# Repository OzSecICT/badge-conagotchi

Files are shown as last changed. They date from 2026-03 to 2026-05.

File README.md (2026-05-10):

# OzSec 2026: Conagotchi

Private repository for the OzSec 2026 Conagotchi badge — an ESP32-S3 interactive badge with a round GC9A01 display, virtual pet (Conagotchi) mode, and CTF challenge mode.

## Setup

Install host tools:

```bash
pip install esptool mpremote Pillow
```

## Flashing MicroPython firmware

```bash
esptool.py --chip esp32s3 --before default-reset --after hard-reset \
    write_flash -z 0x0 firmware/ESP32_GENERIC_S3-SPIRAM_OCT-20251209-v1.27.0.bin
```

## Deploying code

```bash
mpremote cp -r source/. :
mpremote reset
```

The VS Code default task (`Ctrl+Shift+B`) does both steps automatically.

## Converting images for the display

The GC9A01 display is 240×240 pixels round. Images must be converted from PNG to raw RGB565 binary before being copied to the badge — MicroPython cannot decode PNGs at runtime.

### Install the conversion tool dependency

```bash
pip install Pillow
```

### Full-screen backgrounds (240×240)

Design your PNG at 240×240 pixels. The corners outside the circular bezel are never shown, so no special treatment is needed — just design for a circle inscribed in the square.

```bash
python tools/convert_image.py your_image.png --outdir source/img
```

Produces `source/img/your_image.bin` — 115,200 bytes (240 × 240 × 2).

### Character animation frames

The Conagotchi idle animation uses sprite frames sized to the character bounding box (100×115 px by default). Export individual frames from your animation tool as transparent-background PNGs, then convert:

```bash
# Pre-sized PNGs (100×115) — convert without resizing
python tools/convert_image.py char_idle_0.png char_idle_1.png char_idle_2.png char_idle_3.png \
    --no-resize --outdir source/img

# OR crop from a full 240×240 mockup
python tools/convert_image.py mockup_frame0.png --crop 70,52,100,115 \
    --output source/img/char_idle_0.bin
```

The `--crop` coordinates (`x,y,w,h`) match the `_CHAR_X`, `_CHAR_Y`, `_CHAR_W`, `_CHAR_H` constants in `source/screens/conagotchi.py`.

### Menu button sprites

Each navigation button has three states: unselected (baked into the background), selected, and pressed. The selected/pressed states are small sprite files:

```bash
# Pre-sized sprite PNG
python tools/convert_image.py btn_pet_sel.png --no-resize --outdir source/img

# OR crop the button region from a full 240×240 state mockup
# Coordinates match the _BUTTONS table in source/screens/menu.py
python tools/convert_image.py menu_mockup_selected.png --crop 90,5,60,45 \
    --output source/img/btn_pet_sel.bin
```

### Compositing transparent overlays

If your overlay PNG has an alpha channel (transparency), composite it onto the background before converting:

```bash
python tools/convert_image.py background.png overlay.png \
    --composite --output source/img/result.bin
```

### Deploy images to badge

Images live in `source/img/` and are deployed alongside the Python files:

```bash
mpremote cp -r source/. :
```

### Expected image files

| File | Purpose |
|---|---|
| `source/img/logo.bin` | Splash screen background |
| `source/img/{character}/background.bin` | Per-character main screen background (240×240) |
| `source/img/{character}/character.bin` | Idle animation base frame (80×80) |
| `source/img/{character}/idle_1.bin` … | Additional idle animation frames (optional) |
| `source/img/menu_bg.bin` | Menu screen background (all buttons unselected) |
| `source/img/btn_{id}_sel.bin` | Per-button selected state sprite |
| `source/img/btn_{id}_press.bin` | Per-button pressed state sprite |

The active character is set by `_CHARACTER` in `source/screens/conagotchi.py` (currently `"hackachi"`).

All `.bin` files are gitignored — generate them locally from your source PNGs.

## Hardware notes

- IR receiver to be changed to TSOP57438TT1 ([JLCPCB part](https://jlcpcb.com/partdetail/VishayIntertech-TSOP57438TT1/C3742825))

## Diagnostics

Run this on the REPL to check memory and flash:

```python
import gc, sys, esp32, os; gc.collect(); print(f"\n=== MicroPython Info ===\nImplementation: {sys.implementation}\nPlatform: {sys.platform}\nuname: {os.uname()}\n\n=== Memory ===\nFree: {gc.mem_free()/1024:.1f} KB\nUsed: {gc.mem_alloc()/1024:.1f} KB\nTotal: {(gc.mem_free()+gc.mem_alloc())/1024:.1f} KB\n\n=== Heap Regions ==="); [print(f"  {r[0]/1024/1024:.2f} MB total, {r[1]/1024/1024:.2f} MB free, {r[2]} largest block") for r in esp32.idf_heap_info(esp32.HEAP_DATA)]; print(f"\n=== Flash ==="); import esp; print(f"  Flash size: {esp.flash_size()/1024/1024:.0f} MB")
```

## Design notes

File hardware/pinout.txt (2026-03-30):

Badge pinout:

UART
GPIO43  ESP_TX
GPIO44  ESP_RX 

USB
GPIO19  Data-
GPIO20  Data+

JTAG
GPIO5   TCK
GPIO6   TDO
GPIO7   TDI
GPIO8   TMS

I2C
GPIO17  SDA
GPIO18  SCL

Buttons
GPIO0   BOOT
GPIO9   START
GPIO21  SELECT
GPIO46  RIGHT
GPIO47  LEFT

SAO
GPIO38  SAO_GPIO1
GPIO48  SAO_GPIO2

LEDs
GPIO2   ALERT
GPIO4   RAFFLE
GPIO45  RGB Strip (8)

Display/SPI
GPIO10  CS
GPIO11  SDA
GPIO12  SCL
GPIO13  DC
GPIO14  RST

Link / IR
GPIO41  IR_TX
GPIO42  IR_RX

Link / Connector
GPIO39  LINK_TX
GPIO40  LINK_RX

Free pins:
GPIO1
GPIO3

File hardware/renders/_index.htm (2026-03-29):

# Render Browser

/ OzSec2026-ESP32

14 variants · 2 views each

Front Back

## All variants — front view

Black mask / White silk / ENIG (Gold)

Black Gold

Black mask / White silk / HASL (Silver)

Black Silver

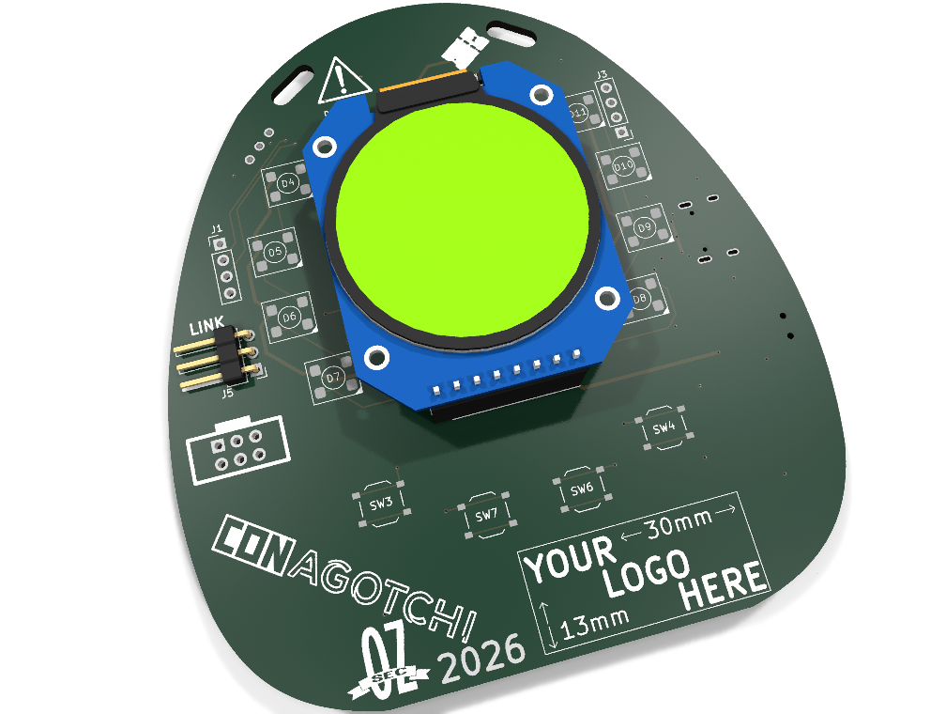
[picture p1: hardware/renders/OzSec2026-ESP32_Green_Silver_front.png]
Green mask / White silk / HASL (Silver)


Green Silver

Purple mask / White silk / HASL (Silver)

Purple Silver

Red mask / White silk / HASL (Silver)

Red Silver

Yellow mask / White silk / HASL (Silver)

Yellow Silver

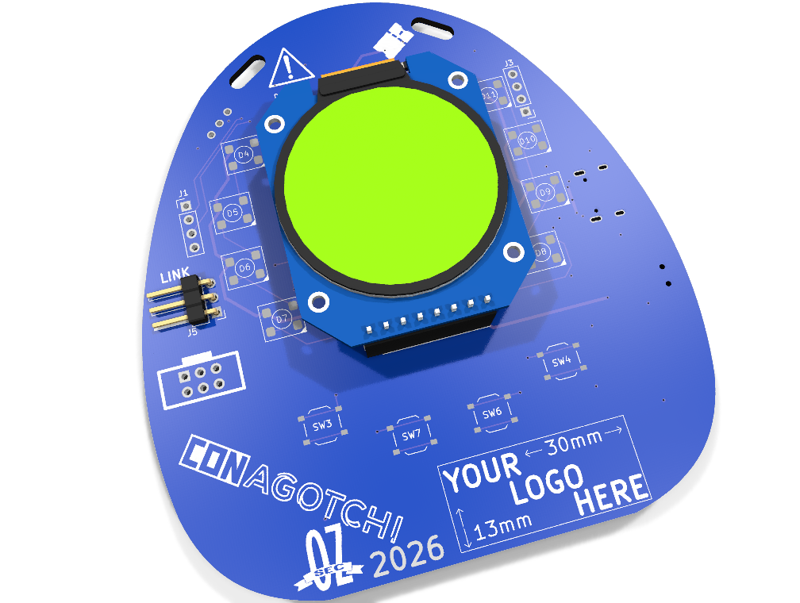
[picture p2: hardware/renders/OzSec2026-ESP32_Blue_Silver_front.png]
Blue mask / White silk / HASL (Silver)


Blue Silver

White mask / Black silk / HASL (Silver)

White Silver

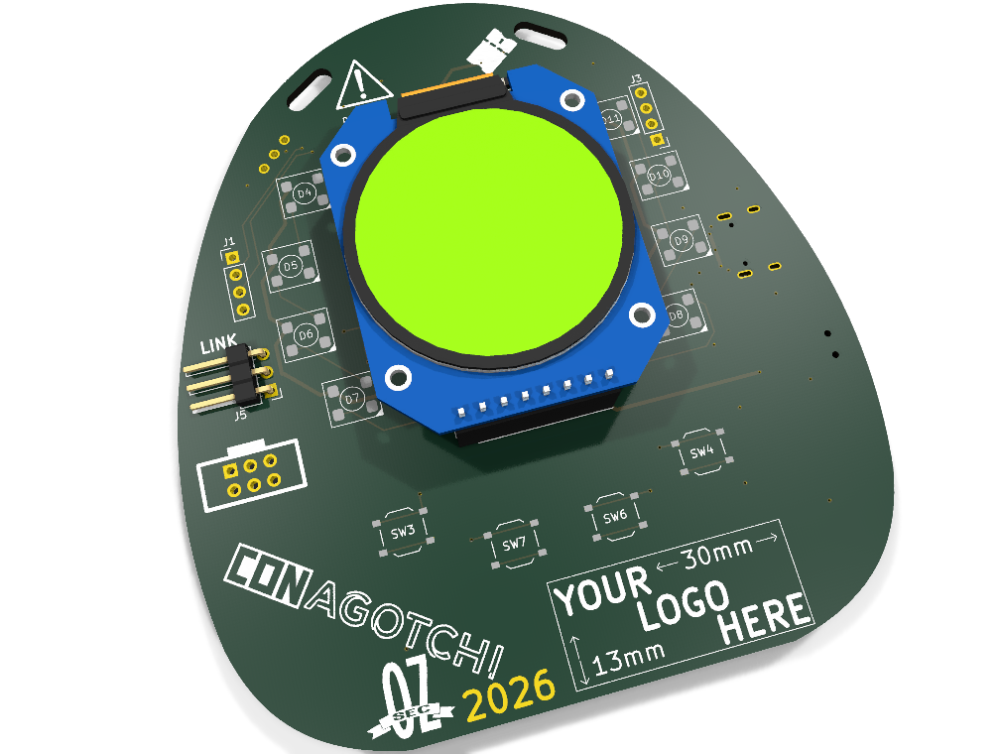
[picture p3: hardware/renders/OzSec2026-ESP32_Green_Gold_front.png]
Green mask / White silk / ENIG (Gold)


Green Gold

Purple mask / White silk / ENIG (Gold)

Purple Gold

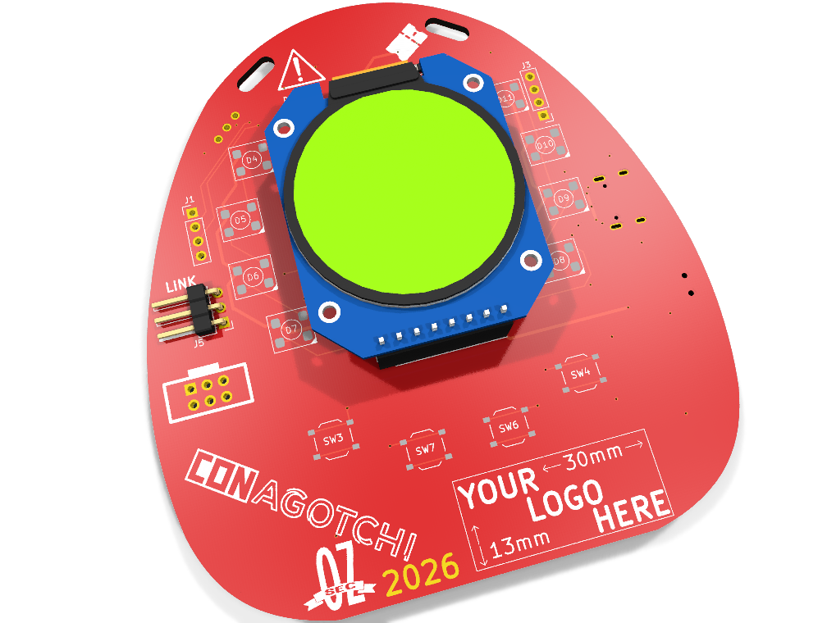
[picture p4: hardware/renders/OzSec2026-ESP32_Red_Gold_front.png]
Red mask / White silk / ENIG (Gold)


Red Gold

Yellow mask / White silk / ENIG (Gold)

Yellow Gold

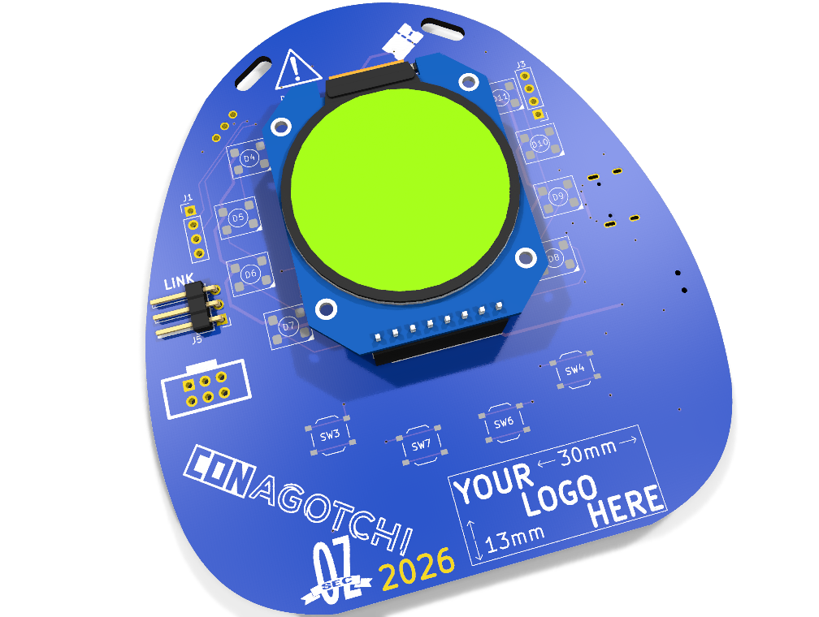
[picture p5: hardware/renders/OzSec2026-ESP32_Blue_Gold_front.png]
Blue mask / White silk / ENIG (Gold)


Blue Gold

White mask / Black silk / ENIG (Gold)

White Gold

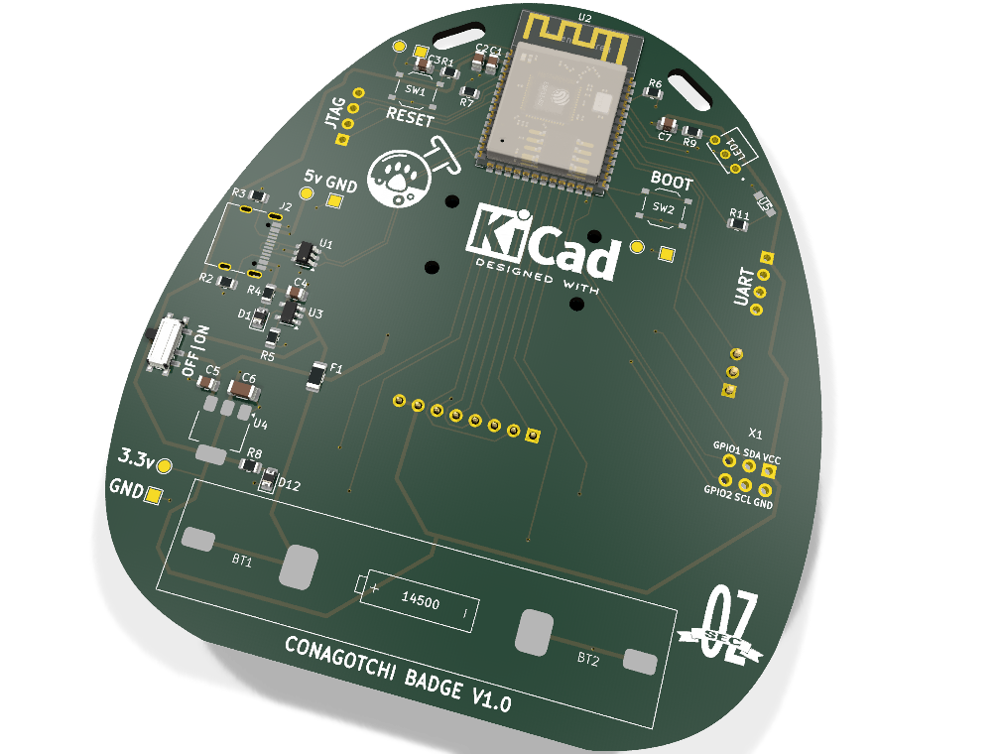
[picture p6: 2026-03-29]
hardware/renders/OzSec2026-ESP32_Green_Gold_back.png

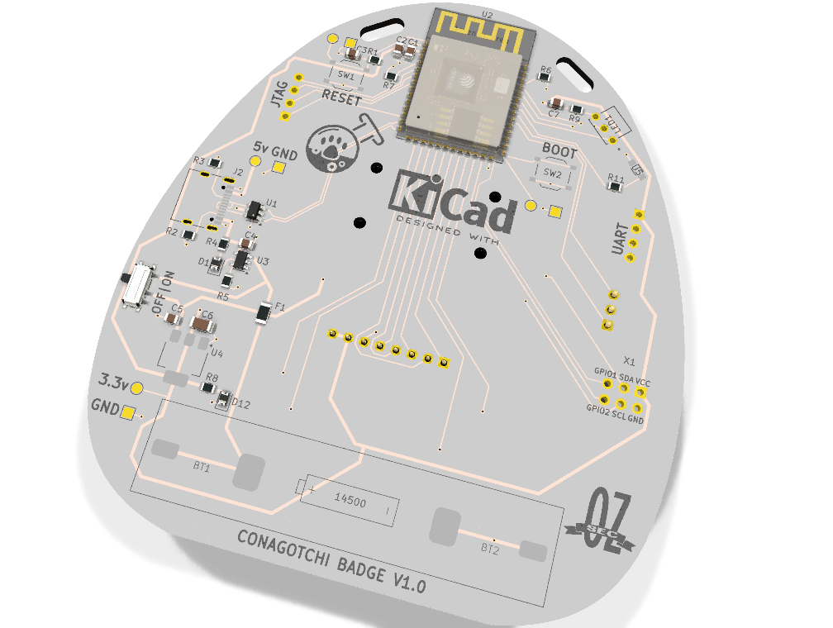
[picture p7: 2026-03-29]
hardware/renders/OzSec2026-ESP32_White_Gold_back.png

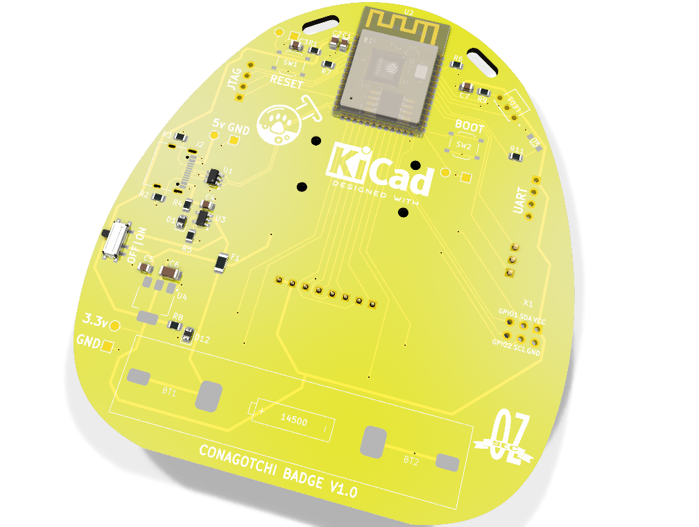
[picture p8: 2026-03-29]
hardware/renders/OzSec2026-ESP32_Yellow_Gold_back.png

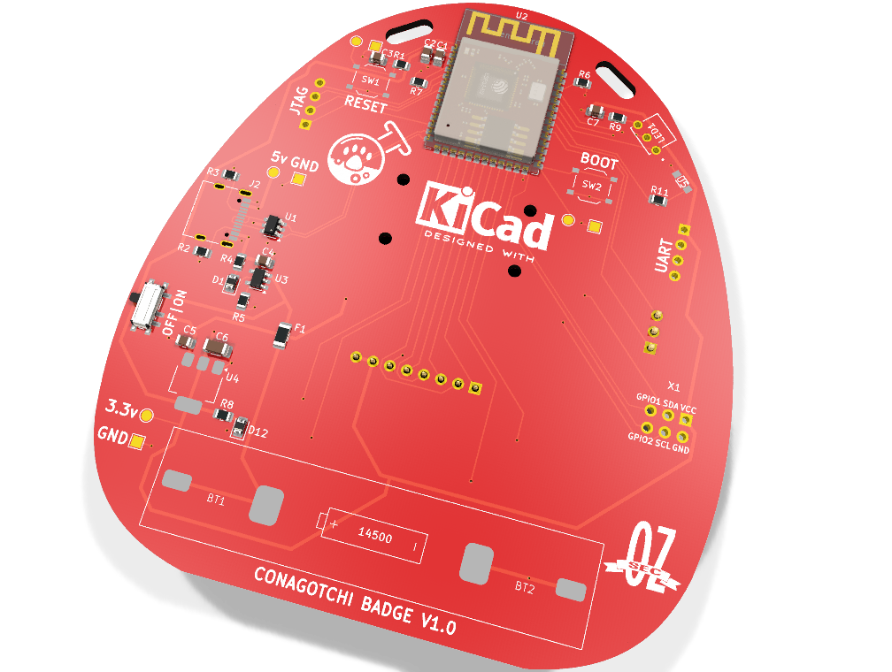
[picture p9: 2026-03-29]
hardware/renders/OzSec2026-ESP32_Red_Gold_back.png

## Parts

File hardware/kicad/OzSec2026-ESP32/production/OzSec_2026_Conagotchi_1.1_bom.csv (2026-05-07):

Designator | Footprint | Quantity | Value | LCSC Part #
BT1_2 | MY-AA-04_Silkscreen_Only | 1 | Battery | C2979179
BT1 | MY-AA-04_BT1A | 1 | ~ | C2979179
BT2 | MY-AA-04_BT1B | 1 | ~ | C2979179
C1 | 0805 | 1 | 22uF | C45783
C2, C6 | 0805 | 2 | 100nF | C49678
C3 | 0805 | 1 | 10uF | C15850
C4 | 0805 | 1 | 1uF | C28323
C5 | 0805 | 1 | 4.7uF | C1779
C7 | 1206 | 1 | 100uF | C15008
D1 | LED_MB14940_VIS | 1 | VSMY14940 | C511069
D10, D11, D12, D5, D6, D7, D8, D9 | D_SMD5050-4P_XL-5050RGBC-2812B | 8 | 2812B | C2843785
D13, D4 | 0805 | 2 | Green | C2297
D2, D3 | 0805 | 2 | Yellow | C2296
F1 | 1206 | 1 | Fuse | C261957
J2 | USB_C_Receptacle_G-Switch_GT-USB-7010ASV | 1 | USB_C_Receptacle_USB2.0 | C2988369
J4 | PinSocket_1x08_P2.54mm_Vertical | 1 | DISPLAY | C42431840
J5 | PinHeader_1x03_P2.54mm_Horizontal | 1 | Conn_01x03_Socket | C492411
R1, R10 | 0805 | 2 | 10k | C17414
R2, R3 | 0805 | 2 | 5.1K | C27834
R4, R6 | 0805 | 2 | 100 | C17408
R5, R8, R9 | 0805 | 3 | 1K | C17513
R7 | 0805 | 1 | 2K | C17604
SW1, SW2 | SW_Push_1P1T_XKB_TS-1187A | 2 | SW_Push | C318884
SW3, SW4, SW6, SW7 | SW-SMD_4P-L4.5-W4.5-P3.00-LS6.8 | 4 | SW_Push | C2888900
SW5 | SW_SPDT_PCM12 | 1 | POWER | C431541
U1 | SOT-23-6 | 1 | USBLC6-2SC6 | C2827654
U2 | ESP32-S3-WROOM-1 | 1 | ESP32-S3-WROOM-1 | C2913201
U3 | TSOP382 | 1 | TSOP38238 | C141632
U4 | TSOT-23-5 | 1 | ME4054BM5G-N | C478383
U5 | TLV1117LV | 1 | TLV1117LV-33 | C15578

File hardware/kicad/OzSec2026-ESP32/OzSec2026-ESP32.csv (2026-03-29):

Reference | Qty | Value | DNP | Exclude from BOM | Exclude from Board | Footprint | Link | LCSC
BT1 | 1 | ~ |  |  |  | RuffLabs:MY-AA-04_BT1A
BT2 | 1 | ~ |  |  |  | RuffLabs:MY-AA-04_BT1B
C1 | 1 | 22uF |  |  |  | Capacitor_SMD:C_0805_2012Metric | https://www.lcsc.com/product-detail/C45783.html | C45783
C2,C5 | 2 | 100nF |  |  |  | Capacitor_SMD:C_0805_2012Metric | https://www.lcsc.com/product-detail/C49678.html | C49678
C3 | 1 | 10uF |  |  |  | Capacitor_SMD:C_0805_2012Metric | https://www.lcsc.com/product-detail/C15850.html | C15850
C4 | 1 | 1uF |  |  |  | Capacitor_SMD:C_0805_2012Metric | https://www.lcsc.com/product-detail/C28323.html | C28323
C6 | 1 | 100uF |  |  |  | Capacitor_SMD:C_1206_3216Metric | https://www.lcsc.com/product-detail/C15008.html | C15008
D1,D2 | 2 | Yellow |  |  |  | Diode_SMD:D_0805_2012Metric | https://www.lcsc.com/product-detail/C2296.html | C2296
D3,D12 | 2 | Green |  |  |  | Diode_SMD:D_0805_2012Metric | https://www.lcsc.com/product-detail/C2296.html | C2297
D4,D5,D6,D7,D8,D9,D10,D11 | 8 | 2812B |  |  |  | RuffLabs:D_SMD5050-4P_XL-5050RGBC-2812B | https://www.lcsc.com/product-detail/C2843785.html | C2843785
F1 | 1 | Fuse |  |  |  | Fuse:Fuse_1206_3216Metric | https://www.lcsc.com/product-detail/C261957.html | C261957
J1 | 1 | UART | DNP |  |  | Connector_PinHeader_2.54mm:PinHeader_1x04_P2.54mm_Vertical
J2 | 1 | USB_C_Receptacle_USB2.0 |  |  |  | Connector_USB:USB_C_Receptacle_G-Switch_GT-USB-7010ASV | https://www.lcsc.com/product-detail/C2988369.html | C2988369
J3 | 1 | JTAG | DNP |  |  | Connector_PinHeader_2.54mm:PinHeader_1x04_P2.54mm_Vertical
J4 | 1 | DISPLAY |  |  |  | Connector_PinSocket_2.54mm:PinSocket_1x08_P2.54mm_Vertical
R1 | 1 | 10k |  |  |  | Resistor_SMD:R_0805_2012Metric | https://www.lcsc.com/product-detail/C17414.html | C17414
R2,R3 | 2 | 5.1K |  |  |  | Resistor_SMD:R_0805_2012Metric | https://www.lcsc.com/product-detail/C27834.html | C27834
R4,R6,R7 | 3 | 1K |  |  |  | Resistor_SMD:R_0805_2012Metric | https://www.lcsc.com/product-detail/C17513.html | C17513
R5,R8 | 2 | 2K |  |  |  | Resistor_SMD:R_0805_2012Metric | https://www.lcsc.com/product-detail/C17604.html | C17604
SW1,SW2,SW3,SW4,SW6,SW7 | 6 | SW_Push |  |  |  | Button_Switch_SMD:SW_Push_1P1T_XKB_TS-1187A
SW5 | 1 | POWER |  |  |  | Button_Switch_SMD:SW_SPDT_PCM12 | https://www.lcsc.com/product-detail/C431541.html | C431541
TP1,TP2,TP3,TP4 | 4 | TestPoint |  |  |  | TestPoint:TestPoint_Pad_D1.5mm
TP5,TP6,TP7,TP8 | 4 | TestPoint |  |  |  | TestPoint:TestPoint_Pad_1.5x1.5mm
U1 | 1 | USBLC6-2SC6 |  |  |  | Package_TO_SOT_SMD:SOT-23-6 | https://www.lcsc.com/product-detail/C2827654.html | C2827654
U2 | 1 | ESP32-S3-WROOM-1 |  |  |  | PCM_Espressif:ESP32-S3-WROOM-1
U3 | 1 | ME4054BM5G-N |  |  |  | Package_TO_SOT_SMD:TSOT-23-5 | https://www.lcsc.com/product-detail/C478383.html | C478383
U4 | 1 | TLV1117LV-33 |  |  |  | Package_TO_SOT_SMD:SOT-223 | https://www.lcsc.com/product-detail/C15578.html | C15578
X1 | 1 | Simple_Addon_v2 | DNP |  |  | Simple_Addon_v2:Simple_Addon_v2-BADGE-2x3

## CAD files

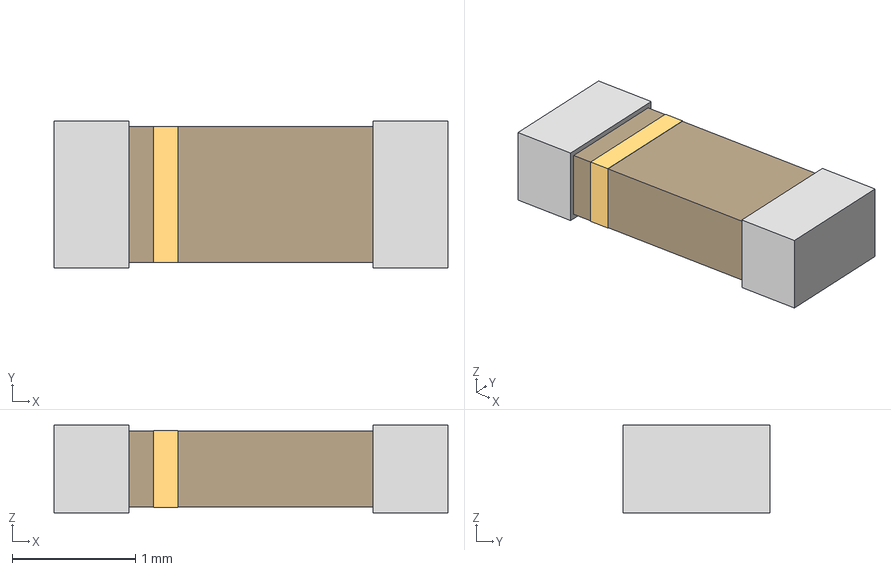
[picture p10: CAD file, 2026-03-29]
hardware/kicad/OzSec2026-ESP32/3dmodels/LED_MB14940_VIS.step
3.20 x 1.19 x 0.711 mm

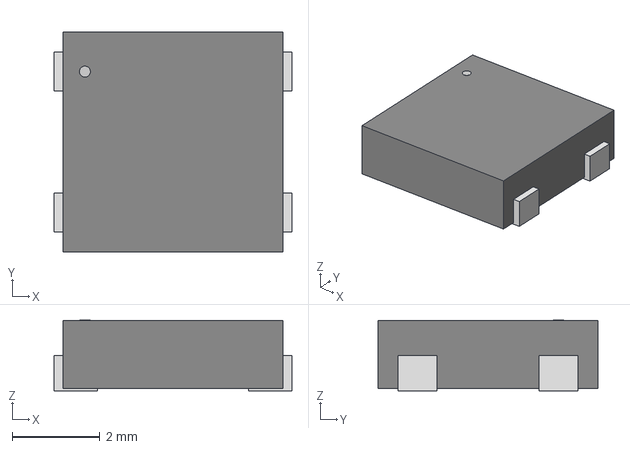
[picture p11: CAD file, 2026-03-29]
hardware/kicad/OzSec2026-ESP32/3dmodels/XL-5050RGBC_XLG.step
5.41 x 5.00 x 1.60 mm

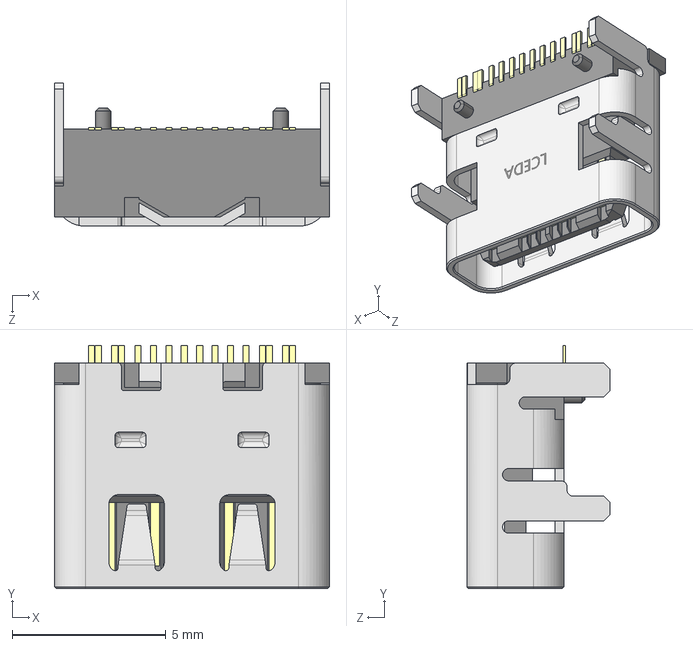
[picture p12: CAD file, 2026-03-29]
hardware/kicad/OzSec2026-ESP32/3dmodels/USB-C-SMD_G-SWITCH_GT-USB-7010ASV.step
8.94 x 7.90 x 4.66 mm

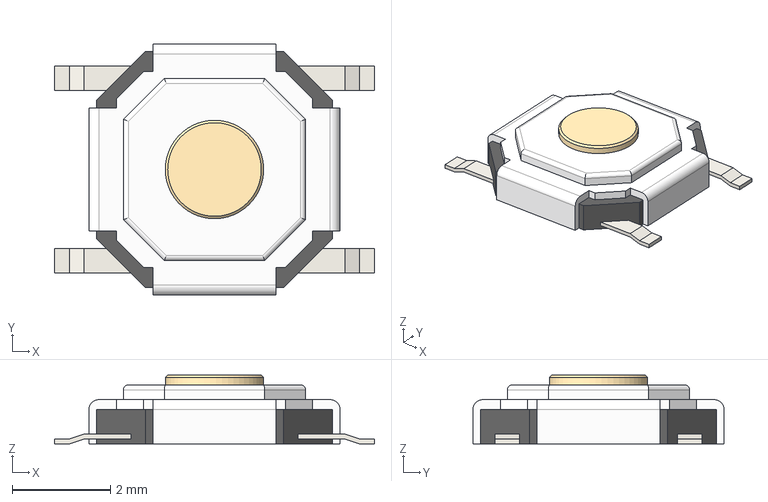
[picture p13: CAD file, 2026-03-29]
hardware/kicad/OzSec2026-ESP32/3dmodels/SW_Push_1P1T_XKB_TS-1187A.step
6.50 x 5.10 x 1.40 mm

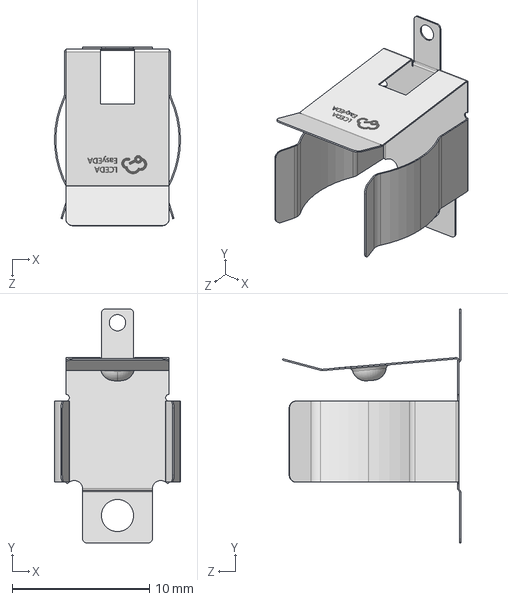
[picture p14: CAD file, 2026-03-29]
hardware/kicad/OzSec2026-ESP32/3dmodels/BAT-SMD_MY-AAA-06.step
9.18 x 17.0 x 13.0 mm

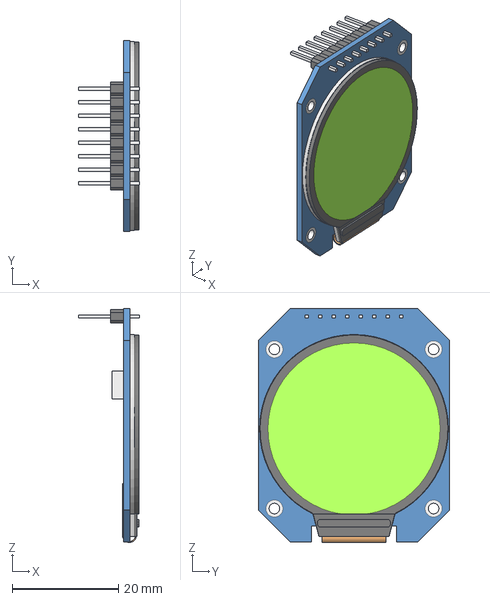
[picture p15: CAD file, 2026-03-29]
hardware/kicad/OzSec2026-ESP32/3dmodels/LCD 1.28 Inch GC9A01.step
11.5 x 36.0 x 44.1 mm

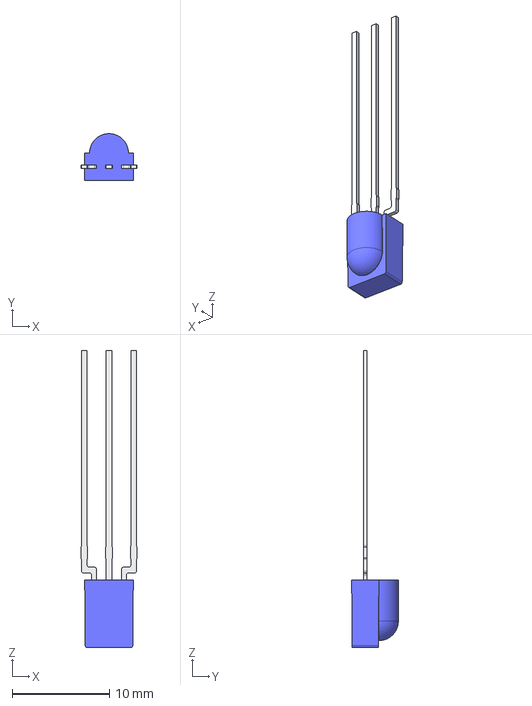
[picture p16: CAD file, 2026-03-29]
hardware/kicad/OzSec2026-ESP32/3dmodels/82687Minicast_SS.stp
5.78 x 4.80 x 30.5 mm
GO-100187
GO-100187.01

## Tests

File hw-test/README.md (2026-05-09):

# OzSec 2026 Badge — Hardware Test

ESP-IDF project for validating badge hardware before firmware development.
Targets the ESP32-S3 with Octal PSRAM.

## What It Tests

The test runs automatically in sequence on boot:

### 1. Display Test
Cycles through 8 visual patterns on the GC9A01 round 240×240 display,
dwelling 1.5 seconds on each before returning automatically:
- Solid fills: Red, Green, Blue, White
- Checkerboard
- Color bars
- RGB gradient
- Crosshair with border

### 2. LED Sequence
Turns on each LED one at a time with 500ms between steps, then turns
them all off:
- ALERT LED (GPIO2)
- RAFFLE LED (GPIO4)
- WS2812B RGB strip (GPIO45) — 8 LEDs lit individually and cumulatively

### 3. Button Test (interactive)
Displays live press/release status for all five buttons. Indicator dots
and label text turn green when a button is held.

- **BOOT** — GPIO0
- **START** — GPIO9
- **SELECT** — GPIO21
- **RIGHT** — GPIO46
- **LEFT** — GPIO47

Once every button has been pressed at least once, the footer prompts
**Hold BOOT to unlock**. Holding BOOT for 500ms turns on all LEDs and
the full WS2812B strip (white). Pressing BOOT again restarts the entire
test sequence from the beginning.

All steps are logged over serial at 115200 baud.

---

## Prerequisites

### Install ESP-IDF with EIM

Espressif IDF Manager (EIM) is the recommended way to install and manage
ESP-IDF versions on macOS and Windows. Download it from:

**https://idf.espressif.com/**

After installing and launching EIM:
1. Select **ESP-IDF v6.0** (or later) and click Install
2. EIM installs the framework and toolchain to `~/.espressif/`

To activate the environment in a terminal session:

```bash
. ~/.espressif/v6.0/esp-idf/export.sh
```

Add an alias to `~/.zshrc` to make this convenient:

```bash
alias get_idf='. ~/.espressif/v6.0/esp-idf/export.sh'
```

> The `export.sh` path will reflect the version EIM installed. Adjust
> `v6.0` if you installed a different version.

---

## Building and Flashing

All commands below should be run from the `hw-test/` directory with the
IDF environment activated.

### Normal build (PSRAM enabled)

```bash
idf.py build flash monitor
```

On first build, or after deleting `sdkconfig`:

```bash
idf.py reconfigure build flash monitor
```

### No-PSRAM build (for boards with faulty or absent PSRAM)

If a board boot-loops with the standard build, its PSRAM is likely
non-functional. Flash a PSRAM-disabled binary:

```bash
rm -f sdkconfig && idf.py -DSDKCONFIG_DEFAULTS=sdkconfig.defaults.nopsram build flash monitor
```

To return to the PSRAM-enabled build afterwards:

```bash
rm -f sdkconfig && idf.py build flash monitor
```

> `rm -f sdkconfig` is required when switching between variants because
> the existing `sdkconfig` file takes precedence over all defaults files.
> Deleting it forces a clean regeneration.

### Flashing note

The badge uses the ESP32-S3 built-in USB (GPIO19/GPIO20). Auto-reset
into download mode is enabled via `CONFIG_ESPTOOLPY_BEFORE="usb_reset"`
in `sdkconfig.defaults` — no manual boot+reset should be required once
firmware is running.

If the board is in a boot loop (and USB never initialises), you will
still need to hold **BOOT + RESET** to enter download mode manually for
that first flash.

---

## Serial Monitor

`idf.py monitor` connects at 115200 baud. Each test phase logs progress:

```
I (xxx) display_test: Pattern 1/8: RED FILL
I (xxx) led_test:     Step 3/11: RGB LED 1 ON (GPIO45, cumulative)
I (xxx) button_test:  START GPIO9   (GPIO 9): PRESSED
I (xxx) button_test:  All buttons pressed! Hold BOOT to activate all LEDs
```

Exit the monitor with **Ctrl+]**.

---

## Pin Reference

| Function | GPIO |
|---|---|
| Display CS | 10 |
| Display MOSI | 11 |
| Display SCK  | 12 |
| Display DC | 13 |
| Display RST  | 14 |
| BOOT button  | 0 |
| START button | 9 |
| SELECT button| 21 |
| RIGHT button | 46 |
| LEFT button  | 47 |
| ALERT LED | 2 |
| RAFFLE LED | 4 |
| RGB strip | 45 |

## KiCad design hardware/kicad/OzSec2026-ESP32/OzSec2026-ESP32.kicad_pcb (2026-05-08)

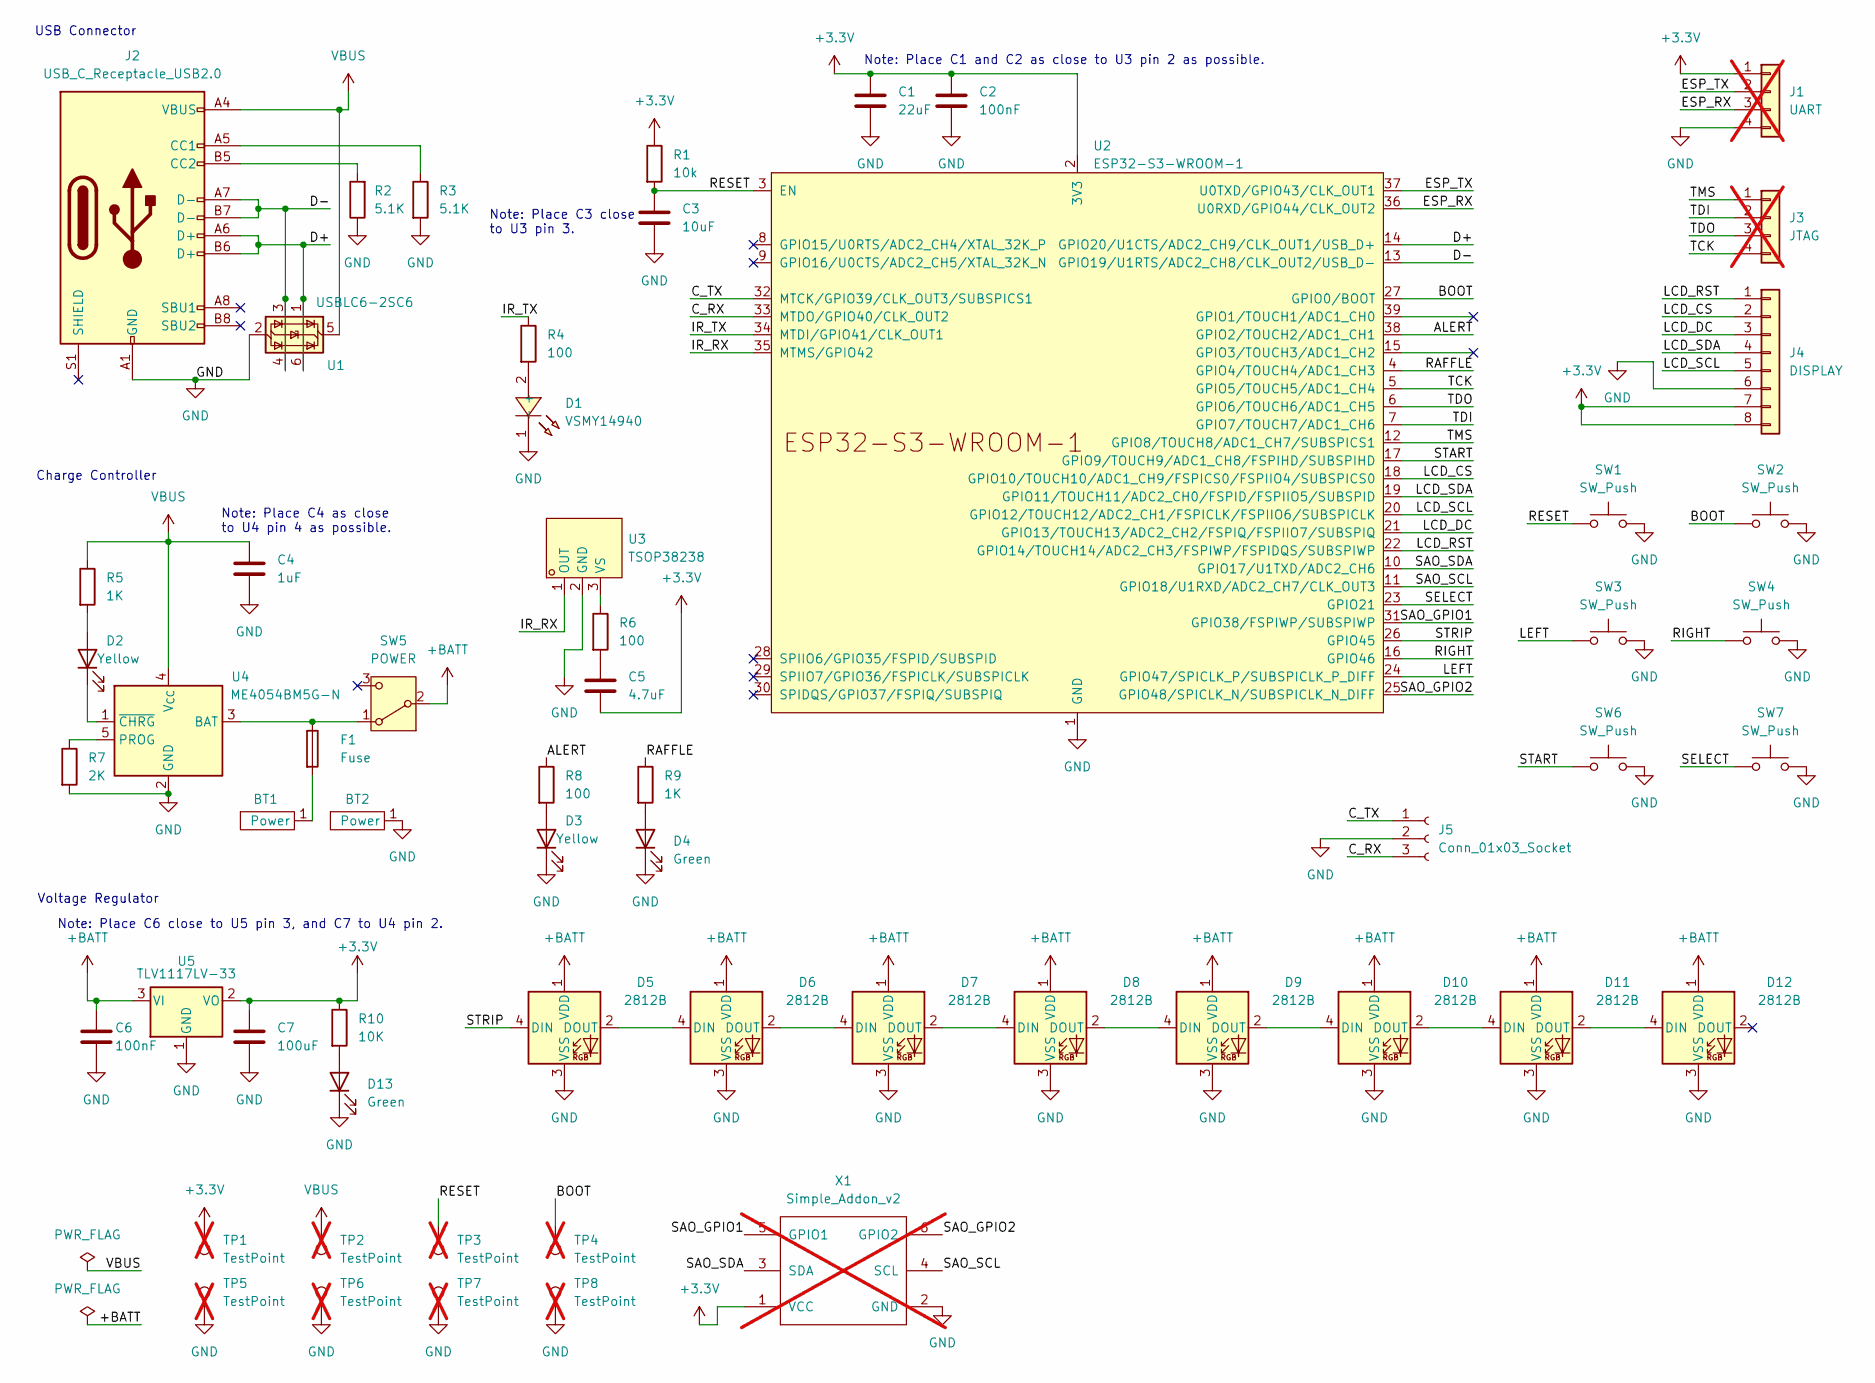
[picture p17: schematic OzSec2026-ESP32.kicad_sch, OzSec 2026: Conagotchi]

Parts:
BT1: MY-AA-04_BT1A; LCSC C2979179
BT2: MY-AA-04_BT1B; LCSC C2979179
C1: 22uF; C_0805_2012Metric; LCSC C45783
C2, C6: 100nF; C_0805_2012Metric; LCSC C49678
C3: 10uF; C_0805_2012Metric; LCSC C15850
C4: 1uF; C_0805_2012Metric; LCSC C28323
C5: 4.7uF; C_0805_2012Metric; LCSC C1779
C7: 100uF; C_1206_3216Metric; LCSC C15008
D1: VSMY14940; LED_MB14940_VIS; LCSC C511069
D2, D3: Yellow; D_0805_2012Metric; LCSC C2296
D4, D13: Green; D_0805_2012Metric; LCSC C2297
D5, D6, D7, D8, D9, D10, D11, D12: 2812B; D_SMD5050-4P_XL-5050RGBC-2812B; LCSC C2843785
F1: Fuse; Fuse_1206_3216Metric; LCSC C261957
J1: UART; PinHeader_1x04_P2.54mm_Vertical; not fitted
J2: USB_C_Receptacle_USB2.0; USB_C_Receptacle_G-Switch_GT-USB-7010ASV; LCSC C2988369
J3: JTAG; PinHeader_1x04_P2.54mm_Vertical; not fitted
J4: DISPLAY; PinSocket_1x08_P2.54mm_Vertical; LCSC C42431840
J5: Conn_01x03_Socket; PinHeader_1x03_P2.54mm_Horizontal; LCSC C492411
R1: 10k; R_0805_2012Metric; LCSC C17414
R2, R3: 5.1K; R_0805_2012Metric; LCSC C27834
R4, R6, R8: 100; R_0805_2012Metric; LCSC C17408
R5, R9: 1K; R_0805_2012Metric; LCSC C17513
R7: 2K; R_0805_2012Metric; LCSC C17604
R10: 10K; R_0805_2012Metric; LCSC C17414
SW1, SW2: SW_Push; SW_Push_1P1T_XKB_TS-1187A; LCSC C318884
SW3, SW4, SW6, SW7: SW_Push; SW-SMD_4P-L4.5-W4.5-P3.00-LS6.8; LCSC C2888900
SW5: POWER; SW_SPDT_PCM12; LCSC C431541
TP1, TP2, TP3, TP4: TestPoint; TestPoint_Pad_D1.5mm; not fitted
TP5, TP6, TP7, TP8: TestPoint; TestPoint_Pad_1.5x1.5mm; not fitted
U1: USBLC6-2SC6; SOT-23-6; LCSC C2827654
U2: ESP32-S3-WROOM-1; LCSC C2913201
U3: TSOP38238; TSOP382; LCSC Part C141632
U4: ME4054BM5G-N; TSOT-23-5; LCSC C478383
U5: TLV1117LV-33; TLV1117LV; LCSC C15578
X1: Simple_Addon_v2; Simple_Addon_v2-BADGE-2x3; LCSC C18164972; not fitted

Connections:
+3.3V: C1.1, C2.1, C5.2, C7.1, J1.1, J4.7, J4.8, R1.1, R10.1, TP1.1, U2.2 (3V3), U5.2 (VO), X1.1 (VCC)
+BATT: C6.1, D5.1 (VDD), D6.1 (VDD), D7.1 (VDD), D8.1 (VDD), D9.1 (VDD), D10.1 (VDD), D11.1 (VDD), D12.1 (VDD), SW5.2 (B), U5.3 (VI)
/ALERT: R8.1, U2.38 (GPIO2/TOUCH2/ADC1_CH1)
/BOOT: SW2.1, TP4.1, U2.27 (GPIO0/BOOT)
/C_RX: J5.3, U2.33 (MTDO/GPIO40/CLK_OUT2)
/C_TX: J5.1, U2.32 (MTCK/GPIO39/CLK_OUT3/SUBSPICS1)
/D+: J2.A6 (D+), J2.B6 (D+), U1.1 (I/O1), U1.6 (I/O1), U2.14 (GPIO20/U1CTS/ADC2_CH9/CLK_OUT1/USB_D+)
/D-: J2.A7 (D-), J2.B7 (D-), U1.3 (I/O2), U1.4 (I/O2), U2.13 (GPIO19/U1RTS/ADC2_CH8/CLK_OUT2/USB_D-)
/ESP_RX: J1.3, U2.36 (U0RXD/GPIO44/CLK_OUT2)
/ESP_TX: J1.2, U2.37 (U0TXD/GPIO43/CLK_OUT1)
/IR_RX: U2.35 (MTMS/GPIO42), U3.1 (OUT)
/IR_TX: R4.1, U2.34 (MTDI/GPIO41/CLK_OUT1)
/LCD_CS: J4.2, U2.18 (GPIO10/TOUCH10/ADC1_CH9/FSPICS0/FSPIIO4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)
/LCD_DC: J4.3, U2.21 (GPIO13/TOUCH13/ADC2_CH2/FSPIQ/FSPIIO7/S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)
/LCD_RST: J4.1, U2.22 (GPIO14/TOUCH14/ADC2_CH3/FSPIWP/FSPIDQS/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)
/LCD_SCL: J4.5, U2.20 (GPIO12/TOUCH12/ADC2_CH1/FSPICLK/FSPIIO6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)
/LCD_SDA: J4.4, U2.19 (GPIO11/TOUCH11/ADC2_CH0/FSPID/FSPIIO5/S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)
/LEFT: SW3.1, U2.24 (GPIO47/SPICLK_P/SUBSPICLK_P_DIFF)
/RAFFLE: R9.1, U2.4 (GPIO4/TOUCH4/ADC1_CH3)
/RESET: C3.1, R1.2, SW1.1, TP3.1, U2.3 (EN)
/RIGHT: SW4.1, U2.16 (GPIO46)
/SAO_GPIO1: U2.31 (GPIO38/FSPIWP/SUBSPIWP), X1.5 (GPIO1)
/SAO_GPIO2: U2.25 (GPIO48/SPICLK_N/SUBSPICLK_N_DIFF), X1.6 (GPIO2)
/SAO_SCL: U2.11 (GPIO18/U1RXD/ADC2_CH7/CLK_OUT3), X1.4 (SCL)
/SAO_SDA: U2.10 (GPIO17/U1TXD/ADC2_CH6), X1.3 (SDA)
/SELECT: SW7.1, U2.23 (GPIO21)
/START: SW6.1, U2.17 (GPIO9/TOUCH9/ADC1_CH8/FSPIHD/SUBSPIHD)
/STRIP: D5.4 (DIN), U2.26 (GPIO45)
/TCK: J3.4, U2.5 (GPIO5/TOUCH5/ADC1_CH4)
/TDI: J3.2, U2.7 (GPIO7/TOUCH7/ADC1_CH6)
/TDO: J3.3, U2.6 (GPIO6/TOUCH6/ADC1_CH5)
/TMS: J3.1, U2.12 (GPIO8/TOUCH8/ADC1_CH7/SUBSPICS1)
GND: BT2.1 (Power), C1.2, C2.2, C3.2, C4.2, C6.2, C7.2, D1.1 (-), D3.1 (K), D4.1 (K), D5.3 (VSS), D6.3 (VSS), D7.3 (VSS), D8.3 (VSS), D9.3 (VSS), D10.3 (VSS), D11.3 (VSS), D12.3 (VSS), D13.1 (K), J1.4, J2.A1 (GND), J2.A12 (GND), J2.B1 (GND), J2.B12 (GND), J4.6, J5.2, R2.1, R3.2, R7.2, SW1.2, SW2.2, SW3.2, SW4.2, SW6.2, SW7.2, TP5.1, TP6.1, TP7.1, TP8.1, U1.2 (GND), U2.1 (GND), U2.40 (GND), U2.41 (GND), U3.2 (GND), U4.2 (GND), U5.1 (GND), X1.2 (GND)
unnamed 33: BT1.1, F1.2; also elsewhere on the board
unnamed: C5.1, R6.2
unnamed: D1.2 (+), R4.2
unnamed: D2.2 (A), R5.2
unnamed: D2.1 (K), U4.1 (~CHRG)
unnamed: D3.2 (A), R8.2
unnamed: D4.2 (A), R9.2
unnamed: D5.2 (DOUT), D6.4 (DIN)
unnamed: D6.2 (DOUT), D7.4 (DIN)
unnamed: D7.2 (DOUT), D8.4 (DIN)
unnamed: D8.2 (DOUT), D9.4 (DIN)
unnamed: D9.2 (DOUT), D10.4 (DIN)
unnamed: D10.2 (DOUT), D11.4 (DIN)
unnamed: D11.2 (DOUT), D12.4 (DIN)
unnamed: D13.2 (A), R10.2
unnamed: J2.A5 (CC1), R3.1
unnamed: J2.B5 (CC2), R2.2
unnamed: F1.1, SW5.1 (A), U4.3 (BAT)
unnamed: R6.1, U3.3 (VS)
unnamed: R7.1, U4.5 (PROG)
VBUS: C4.1, J2.A4 (VBUS), J2.A9 (VBUS), J2.B4 (VBUS), J2.B9 (VBUS), R5.1, TP2.1, U1.5 (VBUS), U4.4 (V_{CC})

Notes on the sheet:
Note: Place C3 close to U3 pin 3.
USB Connector
Note: Place C6 close to U5 pin 3, and C7 to U4 pin 2.
Voltage Regulator
Note: Place C4 as close to U4 pin 4 as possible.
Charge Controller
Note: Place C1 and C2 as close to U3 pin 2 as possible.

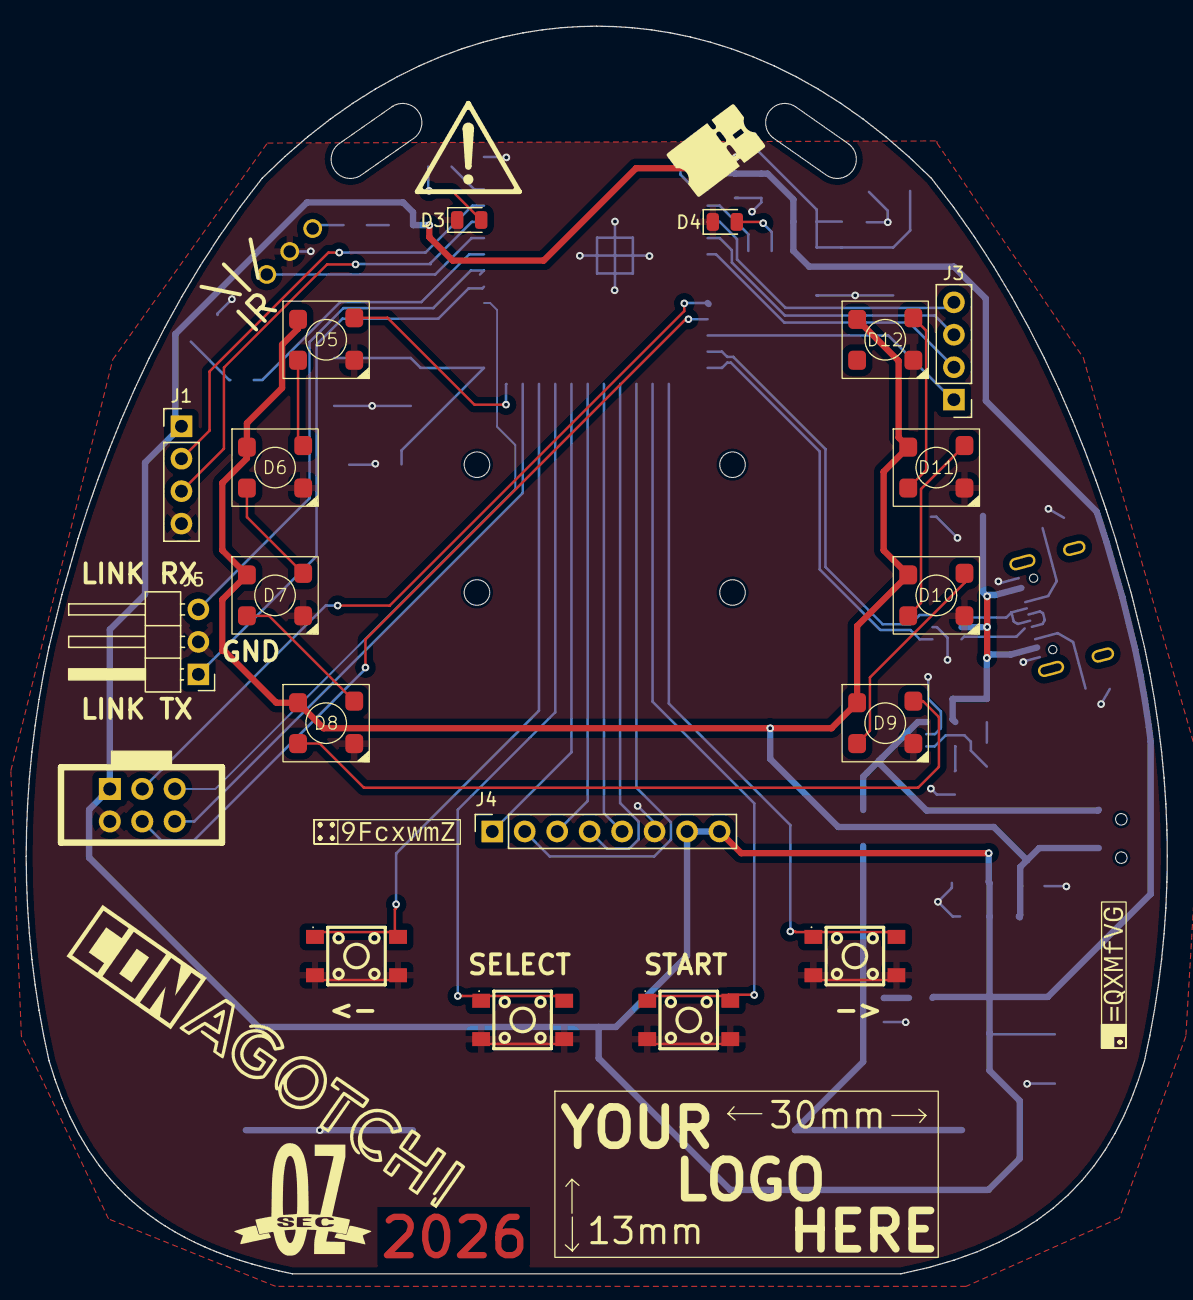
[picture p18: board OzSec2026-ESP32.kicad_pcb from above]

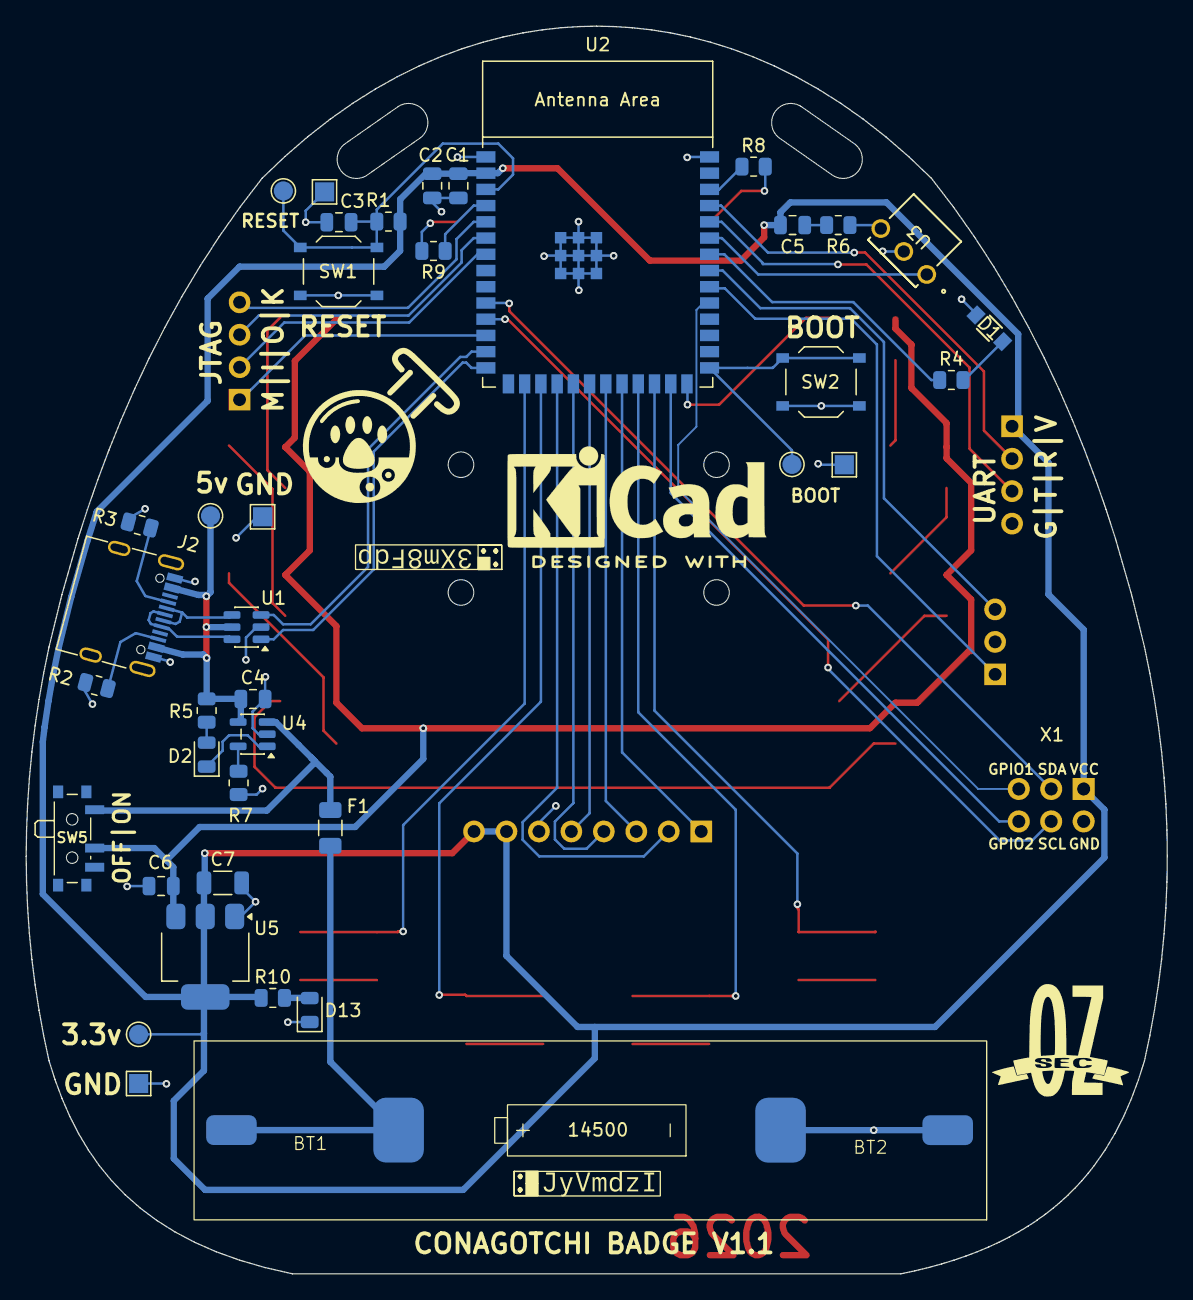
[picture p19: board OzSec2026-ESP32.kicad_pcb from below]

Board: 2 copper layers, 89.3 x 97.6 mm, 60 parts (41 on the bottom side), 54 nets.

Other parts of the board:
BT1#2: MY-AA-04_BT1A

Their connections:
unnamed 33: BT1#2.1 (Power); also elsewhere on the board

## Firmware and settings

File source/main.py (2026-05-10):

import asyncio
import gc

import display as disp
from buttons import Buttons
from leds import Leds
from screen_manager import ScreenManager
from screens.splash import SplashScreen


async def main():
    print("Badge booting...")

    display = disp.init()
    buttons = Buttons()
    leds    = Leds()

    gc.collect()
    print(f"Free RAM: {gc.mem_free()} bytes")

    mgr = ScreenManager(display, leds, buttons)
    await mgr.boot(SplashScreen())

    async def button_loop():
        while True:
            btn = await buttons.get()
            mgr.handle_button(btn)

    async def update_loop():
        while True:
            await mgr.update()
            await asyncio.sleep_ms(33)   # ~30 fps

    print("Badge ready.")
    await asyncio.gather(button_loop(), update_loop())


asyncio.run(main())

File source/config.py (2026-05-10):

# Badge hardware pin assignments and tunable constants.
# Import this everywhere rather than hard-coding pin numbers.

# ── UART ──────────────────────────────────────────────────────────────────────
PIN_UART_TX         = 43
PIN_UART_RX         = 44

# ── I2C (SAO connector) ───────────────────────────────────────────────────────
PIN_I2C_SDA         = 17
PIN_I2C_SCL         = 18

# ── Buttons (active-low, internal pull-up) ────────────────────────────────────
PIN_BTN_BOOT        = 0
PIN_BTN_START       = 9
PIN_BTN_SELECT      = 21
PIN_BTN_RIGHT       = 46
PIN_BTN_LEFT        = 47
DEBOUNCE_MS         = 100

# ── SAO expansion GPIOs ───────────────────────────────────────────────────────
PIN_SAO_GPIO1       = 38
PIN_SAO_GPIO2       = 48

# ── LEDs ──────────────────────────────────────────────────────────────────────
PIN_LED_ALERT       = 2     # Red indicator — character needs attention
PIN_LED_RAFFLE      = 4     # Green indicator — raffle ticket earned
PIN_LED_RGB         = 45    # WS2812B data line
NUM_RGB_LEDS        = 8

# ── Display — GC9A01 240×240 round, SPI ──────────────────────────────────────
PIN_DISP_CS         = 10
PIN_DISP_MOSI       = 11    # Labelled SDA on display silkscreen
PIN_DISP_SCK        = 12    # Labelled SCL on display silkscreen
PIN_DISP_DC         = 13
PIN_DISP_RST        = 14
DISP_WIDTH          = 240
DISP_HEIGHT         = 240
DISP_SPI_FREQ       = 40_000_000

# ── IR badge-to-badge link ────────────────────────────────────────────────────
PIN_IR_TX           = 41
PIN_IR_RX           = 42
IR_FREQ_HZ          = 38_000   # matches TSOP38238 receiver

# ── Wired badge-to-badge link ─────────────────────────────────────────────────
PIN_LINK_TX         = 39
PIN_LINK_RX         = 40
LINK_BAUD           = 115200

# ── WiFi ──────────────────────────────────────────────────────────────────────
WIFI_SSID           = "OzSec 2026"
WIFI_PASSWORD       = "OzSec2026WiFi!"
WIFI_TIMEOUT_S      = 10

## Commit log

2024-10-25 Test code for sample LCD display.
2026-03-29 Add KiCad project
    [82687Minicast_SS.stp, BAT-SMD_MY-AAA-06.step, LCD 1.28 Inch GC9A01.step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]
2026-03-29 Added render.py to generate pcb color options.
2026-03-30 Fabrication files for prototype 1.
    [....productionOzSec_2026_Conagotchi_1.0_bom.csv, ....productionOzSec_2026_Conagotchi_1.0_designators.csv, ....productionOzSec_2026_Conagotchi_1.0_positions.csv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]
2026-03-30 Added silkscreen to LINK connector.
    [OzSec2026-ESP32.kicad_pcb]
2026-05-07 Version 1.1 of PCB and some initial source files.
    [OzSec2026-ESP32.kicad_pcb, OzSec2026-ESP32.kicad_sch, OzSec_2026_Conagotchi_1.1_bom.csv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]
2026-05-08 Update resistor value 1K -> 100R with updated LCSC part (C17408)
    [OzSec2026-ESP32.kicad_pcb, OzSec2026-ESP32.kicad_sch]
2026-05-08 Add hw-test ESP-IDF project for badge hardware validation
    Tests GC9A01 round display, 5 buttons, 2 LEDs, and 8x WS2812B strip
    on ESP32-S3. Auto-sequences display patterns, LED chase, then live
    button status. Holding BOOT after all buttons are pressed lights all
    LEDs; pressing BOOT again restarts the sequence.
    Includes sdkconfig.defaults.nopsram for boards without working PSRAM
    and CONFIG_ESPTOOLPY_BEFORE=usb_reset for auto-flash via built-in USB.
2026-05-09 MicroPython skeleton for badge firmware
    Clean-slate rewrite replacing the old source files. Removes RP2-specific
    typings, tests stub, and old menu/state modules.
    Structure:
    boot.py — minimal gc.collect() before main
    config.py — all pin assignments and tunables in one place
    display.py — GC9A01 SPI init wrapper
    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
2026-05-09 Add ESP32 MicroPython stubs and Pyright/Pylance config for IntelliSense
    Installs micropython-esp32-stubs==1.27.0.post1 into typings/ and
    configures pyrightconfig.json so Pylance resolves machine, network,
    neopixel, etc. without false import warnings.
2026-05-09 Keep WiFi and BLE radios off until explicitly needed
    Wifi.__init__ now calls active(False) to ensure the radio is disabled
    at boot. Removed auto-connect from main.py startup so neither WiFi
    nor BLE consume power unless the application explicitly requests them.
2026-05-10 Fix VS Code tasks failing on macOS due to zsh quoting
    VS Code wraps shell tasks in zsh -l -c, which mangled single quotes in
    nested bash -c strings and triggered zsh glob errors on bare '---'.
    Set options.shell.executable to /bin/bash with -lc args on every task
    so VS Code drives bash directly. Removed redundant osx/linux splits.
    Windows tasks get matching powershell.exe shell options.
2026-05-10 Fix Flash Firmware task: correct filename and deprecated esptool flags
    Firmware file is SPIRAM_OCT variant (not plain S3). Updated esptool
    command and flags to current syntax: esptool, default-reset, hard-reset,
    write-flash.
2026-05-10 Fix asyncio.Queue AttributeError on MicroPython ESP32
    MicroPython's asyncio module does not lazy-load Queue via dot-access;
    it must be imported explicitly from the submodule.
    [buttons.py]
2026-05-10 Replace asyncio.Queue with polled list in Buttons
    asyncio.Queue is not present in the ESP32 v1.27.0 frozen firmware
    build. Use a plain list with a 10ms polling loop in get() instead —
    no asyncio submodule dependencies, works on any MicroPython version.
    [buttons.py]
2026-05-10 Fix double-trigger on button release by debouncing both edges
    Previously IRQ_FALLING only updated _last_ms on registered presses.
    Release bounces (HIGH→LOW during release) arrived after the debounce
    window and were registered as a second press.
    Now: trigger on IRQ_FALLING|IRQ_RISING, always update _last_ms on any
    edge, and only register when the pin is confirmed LOW. Any bounce on
    either edge resets the debounce window, preventing spurious events.
    [buttons.py]
2026-05-10 Updated debounce on buttons
